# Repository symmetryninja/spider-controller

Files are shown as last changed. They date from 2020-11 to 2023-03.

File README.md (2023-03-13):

# spider-controller
A Raspberry Pi based linux system for driving ROS robots

I have a Teensy 3.2 setup as a native joystick.

There's a little hack in the code that when you push both left and right on the joypad buttons, it sends a keyboard `alt` keypress - this is to awaken a touchscreen when you don't have a keyboard plugged in.

## Ros component

This is a very basic joystick bridge, built on ROS2 Humble, it just publishes the joy commands to the ros subsystem.

## hardware Todo's

1. make the sd card more accesible
2. include tindie usbc charger
3. update case to suit charger

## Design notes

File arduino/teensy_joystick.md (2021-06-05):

# Some hacks for teensy Teensy 

Hacks are required to have the device report exactly what I want it to.

I figured this out [here on hamaluik.blog](https://github.com/hamaluik/blog.hamaluik.ca/blob/06a8439fae50b15cb966d33f3b0fdef9378a5c72/posts/2013-10-26-making-a-custom-teensy3-hid-joystick.md)

And used some values from the [freebsd diary usb HID here](https://www.freebsddiary.org/APC/usb_hid_usages.php)

Edits are all in the `Arduino/hardware/teensy/cores/teensy3` folder.

## Changes for file: `usb_desc.h`

After `#elif defined(USB_HID)` block:

```c++
#elif defined(USB_ARCADE)
	#define VENDOR_ID   0x16C0
	#define PRODUCT_ID	0x0489
	#define DEVICE_CLASS	0x03
	#define MANUFACTURER_NAME {'B', 'l', 'a', 'z', 'i', 'n', 'g', 'M', 'a', 'm', 'm', 'o', 't', 'h'}
	#define MANUFACTURER_NAME_LEN 14
	#define PRODUCT_NAME	{'W', 'e', 'd', 'c', 'a', 'd', 'e', ' ', 'C', 'o', 'n', 't', 'r', 'o', 'l', 'l', 'e', 'r'}
	#define PRODUCT_NAME_LEN  18
	#define EP0_SIZE			  64
	#define NUM_ENDPOINTS		 2
	#define NUM_USB_BUFFERS	   30
	#define NUM_INTERFACE		 1
	#define ARCADE_INTERFACE	  0 // Joystick
	#define ARCADE_ENDPOINT	   1
	#define ARCADE_SIZE		   16
	#define ARCADE_INTERVAL	   1
	#define ARCADE_DESC_OFFSET  (9)
	#define CONFIG_DESC_SIZE  (9 + 9+9+7)
	#define ENDPOINT1_CONFIG  ENDPOINT_TRANSIMIT_ONLY
```

## Changes for file: `usb_desc.c`

After first instance of `#endif // JOYSTICK_INTERFACE`

```c++
#ifdef ARCADE_INTERFACE
static uint8_t arcade_report_desc[] = {
	0x05, 0x01,					// USAGE_PAGE (Generic Desktop)
	0x09, 0x04,					// USAGE (Joystick)
	0xa1, 0x01,					// COLLECTION (Application)
	0x09, 0x04,					//   USAGE (Joystick)
	0xa1, 0x00,					//   COLLECTION (Physical)
	0x09, 0x30,					//	 USAGE (X)
	0x09, 0x31,					//	 USAGE (Y)
	0x09, 0x33,					//	 USAGE (Rx)
	0x09, 0x34,					//	 USAGE (Ry)
	0x75, 0x08,					//	 REPORT_SIZE (8)
	0x95, 0x04,					//	 REPORT_COUNT (4)
	0x45, 0x7f,					//	 PHYSICAL_MAXIMUM (127)
	0x35, 0x81,					//	 PHYSICAL_MINIMUM (-127)
	0x81, 0x02,					//	 INPUT (Data,Var,Abs)
	0x05, 0x09,					//	 USAGE_PAGE (Button)
	0x19, 0x01,					//	 USAGE_MINIMUM (Button 1)
	0x29, 0x10,					//	 USAGE_MAXIMUM (Button 16)
	0x15, 0x00,					//	 LOGICAL_MINIMUM (0)
	0x25, 0x01,					//	 LOGICAL_MAXIMUM (1)
	0x75, 0x01,					//	 REPORT_SIZE (1)
	0x95, 0x10,					//	 REPORT_COUNT (16)
	0x81, 0x02,					//	 INPUT (Data,Var,Abs)
	0xc0,						//   END_COLLECTION
	0xc0						// END_COLLECTION
};
#endif
```

After second instance of `#endif // JOYSTICK_INTERFACE`

```c++
#ifdef ARCADE_INTERFACE
static uint8_t arcade_report_desc[] = {
	0x05, 0x01,					// USAGE_PAGE (Generic Desktop)
	0x09, 0x04,					// USAGE (Joystick)
	0xa1, 0x01,					// COLLECTION (Application)
	0x09, 0x04,					//   USAGE (Joystick)
	0xa1, 0x00,					//   COLLECTION (Physical)
	0x09, 0x30,					//	 USAGE (X)
	0x09, 0x31,					//	 USAGE (Y)
	0x09, 0x33,					//	 USAGE (Rx)
	0x09, 0x34,					//	 USAGE (Ry)
	0x75, 0x08,					//	 REPORT_SIZE (8)
	0x95, 0x04,					//	 REPORT_COUNT (4)
	0x45, 0x7f,					//	 PHYSICAL_MAXIMUM (127)
	0x35, 0x81,					//	 PHYSICAL_MINIMUM (-127)
	0x81, 0x02,					//	 INPUT (Data,Var,Abs)
	0x05, 0x09,					//	 USAGE_PAGE (Button)
	0x19, 0x01,					//	 USAGE_MINIMUM (Button 1)
	0x29, 0x10,					//	 USAGE_MAXIMUM (Button 16)
	0x15, 0x00,					//	 LOGICAL_MINIMUM (0)
	0x25, 0x01,					//	 LOGICAL_MAXIMUM (1)
	0x75, 0x01,					//	 REPORT_SIZE (1)
	0x95, 0x10,					//	 REPORT_COUNT (16)
	0x81, 0x02,					//	 INPUT (Data,Var,Abs)
	0xc0,						//   END_COLLECTION
	0xc0						// END_COLLECTION
};
#endif
```

near the bottom of the file, add (just below the #ifdef JOYSTICK_INTERFACE ... #endif section)

```c++
#ifdef ARCADE_INTERFACE
		{0x2200, ARCADE_INTERFACE, arcade_report_desc, sizeof(arcade_report_desc)},
		{0x2100, ARCADE_INTERFACE, config_descriptor+ARCADE_DESC_OFFSET, 9},
#endif
```

## Changes for file: `usb_inst.cpp`

Below the `#ifdef JOYSTICK_INTERFACE` block

```c++
#ifdef USB_ARCADE
usb_arcade_class Arcade;
uint8_t usb_arcade_class::auto_send = 0;
#endif
```

## Changes for file: `WProgram.h`

Below `#include "usb_joystick.h"`

```c++
#include "usb_arcade.h"
```

Finally, in order to actually make the Arduino environment use the new arcade descriptors, add the following lines to the file Arduino/hardware/teensy/boards.txt (after the `teensy31.menu.usb.flightsim` entries):

```
teensy3.menu.usb.arcade.name=Wedcade Controller
teensy3.menu.usb.arcade.build.define0=-DUSB_ARCADE
teensy3.menu.usb.arcade.fake_serial=teensy_gateway
```

## Extra files
Copy `usb_arcade.h` & `usb_arcade.c` to `Arduino/hardware/teensy/cores/teensy3` folder.

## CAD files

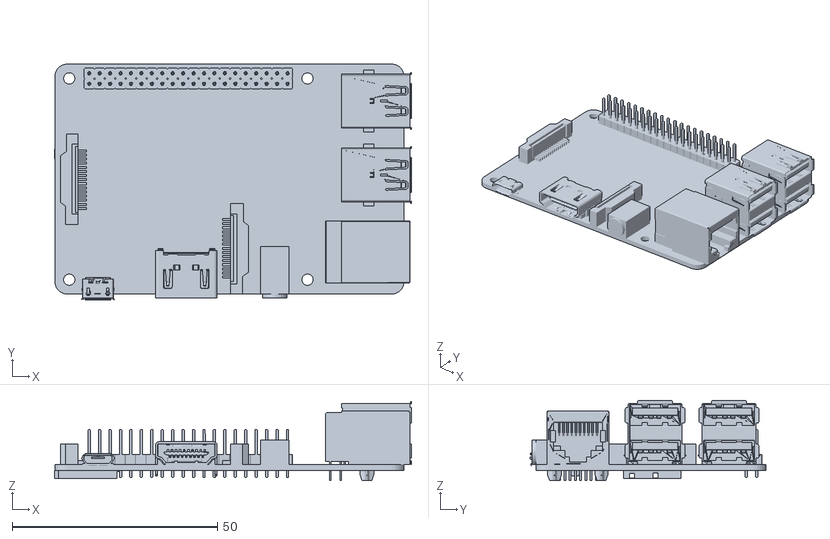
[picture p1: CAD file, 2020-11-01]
3dmodels/stl/pi3BModel.stl
86.9 x 57.4 x 19.6

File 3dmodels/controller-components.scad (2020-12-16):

  // momentary button & cap

  module component_momentary_button_12_cap() {
    translateZ(6) ccylinder(d = 13, h = 1.4);
    translateZ(8) ccylinder(d = 11.5, h = 5.2);
  }

  module component_momentary_button_12() {
    // base
    black() ccube([12,12,3.6]);
    // legs
    silver() mirrorX() mirrorY() translate([3.2, 6, -2]) ccube([1,1, 4.5]);
    // button
    translateZ(2.8) ccube([4,4,7]);
  }

  module component_slider(position = 50, for_cutout=false) {
    silver()
    ccube([45.2, 7.6, 7]);
    silver()
    translateX((position/100 * 30) - 15)
    translateZ(7.5) ccube([5, 1.2, 21.5]);
    if (for_cutout) {
      translateZ(7.5) ccube([46, 3, 21.5]);
    }
  }

  module component_momentary_barrel() {
    translateZ(-14.5) {
      black() translateZ(25.1) ccylinder(d = 5.9, h = 3.8);
      silver() translateZ(21.65) ccylinder(d = 4.7, h = 4.1);
      silver() translateZ(16.1) ccylinder(d = 6.5, h = 8);
      silver() translateZ(13) ccylinder(d = 9.4, h = 2.2);
      black() translateZ(9) ccylinder(d = 7.5, h = 6);
      silver() translateZ(3) mirrorX() translateX(1.9) ccube([0.6, 2, 6]);
    }
  }

  module component_barrel_power_switch(for_cutout = false) {
    full_H = 34;
    if (for_cutout) {
      // square block
      translateZ(full_H/2 - 23)
      ccube([15,22,15]);
    }
    black() {
      // barrel lg
      translateZ(full_H/2 - 12.5)
      ccylinder(d = 12, h = 15);
      // barrel sm
      translateZ(-3.25)
      ccylinder(d = 10, h = full_H-6.5);
      // sq button
      translateZ(full_H/2 - 5.5)
      ccube([11,11,11]);
      // sq barrel
      translateZ(full_H/2 - 7.5)
      ccube([15,15,6.5]);
    }
    silver() {
      // pins
      translateZ(-full_H/2) {
        translateY(3) ccube([2, 0.5, 10]);
        translateY(-3) ccube([2, 0.5, 10]);
      }
    }
  }

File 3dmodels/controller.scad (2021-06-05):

include <sn_tools.scad>
include <power_supplies.scad>
include <controller-components.scad>

/** project


  Phase 1: working with controller mounted and wired
    * core
      * screen frame fixes
        * side buttons (screen momentary switches)
        * increase space between frame and screen by 2 mm

  phase 2: joystick working

  phase 3: Charger

**/

/** Fixes
  * Top/all panel
    * cut a hole/holes for the xt60 pin mount.
  * underside panel
    * print outside up and raised completely off the bed for better removal of supports
*/


/** Scripting stuff **/
  batch_rendering = false;
  if (!batch_rendering) render_workspace();

  module render_workspace() {
    // $fn = 60;
    // sc_place_components();
    // sc_shell_screen_frame();
    // intersection() {
        purple() sc_shell_top();
        // translate([80, 55, 10]) ccube([40,40,15]);}
        translateZ(-5.2) blue() sc_shell_bottom_plate();
      translateZ(-10.1) red() sc_shell_bottom_battery();
  }

/** tooling modules **/

// parts to print
  module sc_parts_for_print() {
    // 
  }

/** globals **/
  sc_joystick_offset = [-113.5, -38, 2];
  sc_screen_offset = [0, 0, 10];
  sc_battery_rotation = [180, 0, 0];
  sc_battery_offset = [-42, 43, -7];
  sc_pi_offset = [30, -30, -8];
  sc_pi_rotation = [180, 0, -90];
  sc_teensy_offset = [-38, -40,-4];
  sc_teensy_rotation = [180, 0, -90];
  sc_bucky_offset = [-31, 0, -4];
  sc_bucky_rotation = [180, 0, 90];
  sc_trigger_offset = [145, -60, 0];

  sc_button_board_offset_R = [-110, 30, 5];
  sc_button_board_offset_L = [-sc_button_board_offset_R[0], sc_button_board_offset_R[1], sc_button_board_offset_R[2]];
  sc_button_board_rotation_Z = 90;

  sc_power_switch_offset= [67, -65, -15];
  sc_power_switch_rotation= [90, 0, 0];
  sc_xt60_offset = [-69,-65,-10];
  sc_xt60_rotation = [90,90,0];
  sc_screen_pi_lugs = [58,49];

/** non-print parts **/
  module sc_place_components() {
    // power switch
    translate(sc_power_switch_offset) rotate(sc_power_switch_rotation) component_barrel_power_switch();
    // xt60
    translate(sc_xt60_offset) rotate(sc_xt60_rotation) xt_60_plug_with_panel(cutouts_only = false);
    // buttons
      // left & right stick
      mirrorX() translate(sc_joystick_offset) sc_joystick();

    sc_button_board_L();
    sc_button_board_R();

    // batteries
      mirrorX() translate(sc_battery_offset) rotate(sc_battery_rotation) battery_holder_dual_18650(withBatteries=true);

    // screen 
      translate(sc_screen_offset) sc_screen();
    // boards
      // pi
      translate(sc_pi_offset) rotate(sc_pi_rotation) import("stl/pi3BModel.stl", convexity=3);

      // teensy
      translate(sc_teensy_offset) rotate(sc_teensy_rotation) sc_board_teensy();

      // bucky
      translate(sc_bucky_offset) rotate(sc_bucky_rotation) sc_bucky();

      // triggers
      mirrorX() translate(sc_trigger_offset) sc_triggers();
  }

  module sc_bucky() {
    green()
    difference() {
      ccube([37, 47, 1.5]);
      #sc_bucky_screws();
    }
  }

  module sc_bucky_screws(d=2.9, h=2) {
    mirrorX() translateX(15)
      translateY(42/2)
      ccylinder(h = h, d = d);
    translateX(-15)
      translateY(-38/2)
      ccylinder(h = h, d = d);
    translateX(15)
      translateY(-42/2)
      ccylinder(h = h, d = d);

  }

  module sc_bucky_test() {
    difference() {
      union() {
        hull() {
          sc_bucky_screws(d=6, h=2);
        }
        translateZ(4)
          sc_bucky_screws(d=6, h=8);
      }
      union() {
        sc_bucky_screws(h = 20);
      }
    }
  }

// components

  module sc_pushbutton(cap_color="white", os = 0) {
    translateZ(1.5)
    color(cap_color) {
      ccylinder(d=9 + os, h=14.5);
      translateZ(-3.7) ccylinder(d=12 + os, h=7.2);
    }
  }
  
  module sc_button_board_R() {
    translate(sc_button_board_offset_R) sc_button_board();
  }

  module sc_button_board_L() {
    translate(sc_button_board_offset_L) mirror([1,0,0]) sc_button_board(col_1="DarkSlateGray", col_2="DarkSlateGray", col_3="DarkSlateGray", col_4="DarkSlateGray");
  }

  module sc_button_board_panel_extras() {
    translate(sc_button_board_offset_R) sc_button_board_panel_extra();
    translate(sc_button_board_offset_L) mirror([1,0,0]) sc_button_board_panel_extra();
  }

  module sc_button_board_panel_extra() {
    rotateZ(sc_button_board_rotation_Z)
    union() {
      translateZ(5.3) {
        make_drill_holes(size=[66,46,9], shaftD=6);
        translate([-13.68, 0.7, 0])
        ccylinder(d = 6, h = 9);
      }
    }
  }

  module sc_button_board_cutouts() {
    translate(sc_button_board_offset_R) sc_button_board_cutout();
    translate(sc_button_board_offset_L) mirror([1,0,0]) sc_button_board_cutout();
  }

  module sc_button_board_cutout() {
    rotateZ(sc_button_board_rotation_Z) {
      // screws
      make_drill_holes(size=[66,46,25], shaftD=2.6);

      // slider cut out
      translate(sc_slider_R_offset) rotateZ(90) component_slider(for_cutout=true);
    }

    // buttons
    sc_button_board(os=1.5);
  }

  sc_trigger_R_offset = [0, -20, -12];
  sc_button_group_R_offset = [-20, 0, 7];
  sc_slider_R_offset = [24.85, 0, 4.5];

  module sc_button_board(col_1="DarkSlateGray", col_2="red", col_3="green", col_4="yellow", os=0) {
    rotateZ(sc_button_board_rotation_Z) {
      // green board
      rotateZ(90) make_protoboard_50_70();
      // iec box
      translate([23,0,-6])
      black() ccube([9, 28, 9.9]);
      // right slider
      translate(sc_slider_R_offset) rotateZ(90) component_slider();
      // right x buttons
        translate([11.5, -19, 7])
          sc_pushbutton("white", os=os);

        // 23.5 36.44
        translate([-1.44, -19, 7])
          sc_pushbutton("white", os=os);

      translate([-13.68, 0.7, 7]) {

        translate([12.7, 0, 0])
          sc_pushbutton(col_1, os=os);

        translate([-12.7, 0, 0])
          sc_pushbutton(col_2, os=os);

        translate([0, 12.7, 0])
          sc_pushbutton(col_3, os=os);

        translate([0, -12.7, 0])
          sc_pushbutton(col_4, os=os);
      }
    }
  }

  module sc_triggers() {
    // triggers
      translate([0,-5,6]) rotateX(90) component_momentary_barrel();
      translate([0,-5,-6]) rotateX(90) component_momentary_barrel();
  }

  // joystick
    module sc_joysticks_cutouts() {
      mirrorX() translate(sc_joystick_offset) sc_joystick(for_cutout = true);
    }

    module sc_joystick_inv(for_cutout = false) {
      mirror([1, 0, 0]) sc_joystick(for_cutout = for_cutout);
    }

    module sc_joystick(for_cutout = false) {
      // shaft
      silver()
      translateZ(12.5) ccylinder(d=8, h = 50);
      difference() {
        union(){
          // lock/unlock
          if (for_cutout) {
            // round
            ccylinder(d = 44, h = 40);
            //component cutout
            translateZ(-5)
            ccube([58, 58, 28]);
            translate([24, 0, -13.65]) 
              rotateY(90) rotateZ(-90)make_pie_slice(d=60, h = 6, angle=80);

            translate([20, 0, 15])
              ccube([5, 20, 20]);
            make_drill_holes(size=[39,39,25], shaftD=6);
            make_drill_holes(size=[39,39,40], shaftD=2.5);
          }
          else {
            //component cutout
            translateZ(-5)
            %ccube([58, 58, 28]);
            // square
            translate([0, 1, -1.25]) ccube([43, 45, 23]);
            make_drill_holes(size=[39,39,25], shaftD=5);

            black() {
              // round
              ccylinder(d = 42, h = 25);
              // crosshair
              translateZ(0.8) {
                ccube([1, 37, 25]);
                ccube([37, 1, 25]);
              }
            }
            translate([24, 0, -5]) {
              rotateY(90) rotateZ(-90)make_pie_slice(d=40, h = 4.5, angle=70);
              rotateY(90) rotateZ(-10)make_pie_slice(d=30, h = 3, angle=200);
              translateZ(16) ccube([3.5, 6, 20]);
            }
          }
        }
        union() {
          if (!for_cutout) black() sc_joystick_cutouts();
        }
      }
    }

    module sc_joystick_cutouts() {
      // top screws
      make_drill_holes(size=[39,39,30], shaftD=2.5);

      // upper cavity
      difference() {
        hull() {
          translateZ(13)
          ccube([30, 22, 1]);
          translateZ(5)
          ccube([25, 15, 1]);
        }
        translateZ(-5)
        rotateY(90)
        ccylinder(d = 30, h = 35);
      }
    }


  // screen
    module sc_screen(for_cutout=false) {
      difference() {
        union() {
          black() {
            // panel
            translateZ(2.2)
            ccube([167, 102, 6.18]);
            
            // power plug
            translate([67.5,-20.5,-5]) ccube([10,15, 20]);

            // usb touch plug
            translate([65,20.5,-5]) ccube([15,20, 20]);
            
            // side buttons
            translate([-77.5, 0, -7]) ccube([13, 55, 15]);
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

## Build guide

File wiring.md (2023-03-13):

# Wiring 

## Button pad wiring

## Button pads

| underside Pin Layout |  left layout | right layout |
| - | - | - |
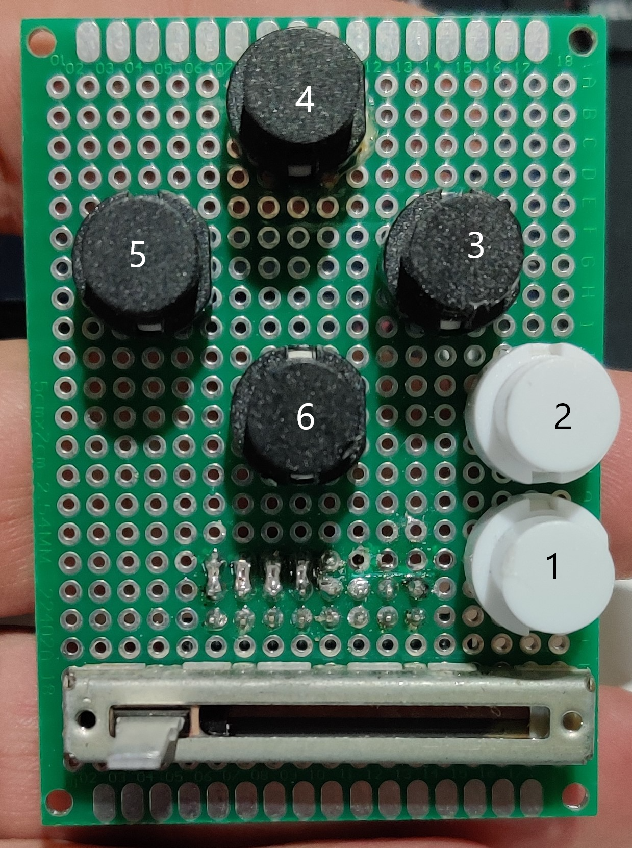
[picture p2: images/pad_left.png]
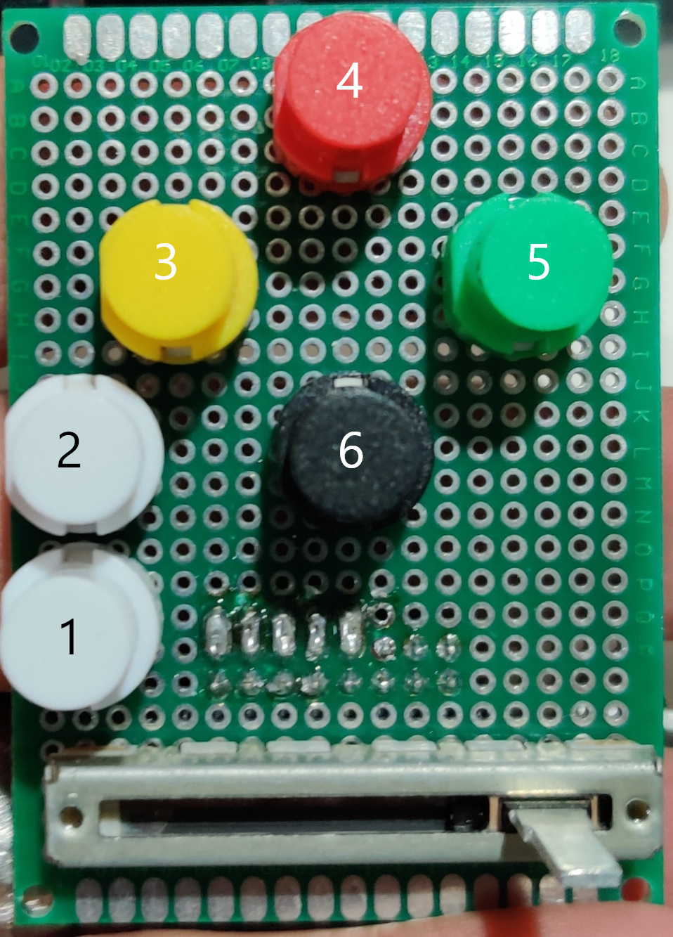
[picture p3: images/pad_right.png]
|  |  |  |

| Pin | purpose | Teensy Pin L  | Teensy Pin R |
|-|-|-|-|
| 0 | negative | A GND | A GND |
| 1 | positive | 3.3 | 3.3 |
| 2 | stick button  | 20 | nc |
| 3 | stick 0 | (17) A3 | A10 |
| 4 | stick 1 | (18) A4 | A11 |
| 5 | slide | (19) A5 | A14 |
| 6 | trigger T | 21 | 3 |
| 7 | trigger B | 22 | 2 |
| 8 | nc | | |
| 9 | nc | | |
| 10 | button 6 | 10 | 9 |
| 11 | button 5 | 11 | 8 |
| 12 | button 4 | 12 | 7 |
| 13 | button 3 | 23 | 6 |
| 14 | button 2 | 16 | 5 |
| 15 | button 1 | 15 | 4 |

## Teensy pinouts

|Teensy front|teensy back|
|-|-|
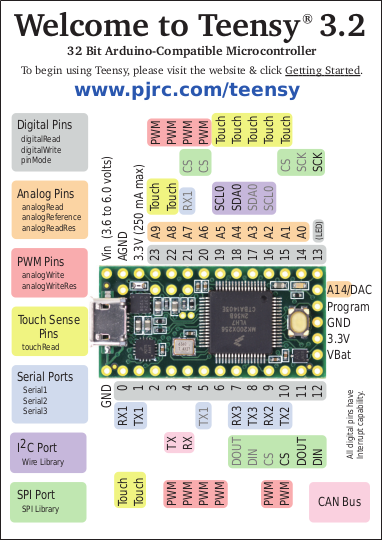
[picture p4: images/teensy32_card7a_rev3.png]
teensya
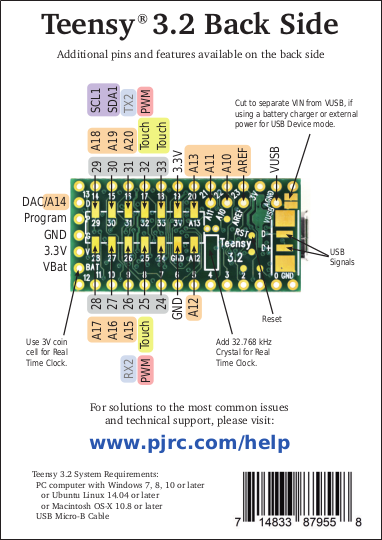
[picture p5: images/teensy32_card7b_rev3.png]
teensyb
| |  |

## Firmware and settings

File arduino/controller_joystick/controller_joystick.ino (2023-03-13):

// #include <Timer.h>                  // A rather useful timer library to offset the comms loop requirement to the motion requirement

// pin definitions 
  #define L_STICK_UD      A3
  #define L_STICK_LR      A4
  #define L_SLIDE         A5
  #define L_TRIGGER_T     21
  #define L_TRIGGER_B     22
  #define L_BUTTON_1      15
  #define L_BUTTON_2      16
  #define L_BUTTON_3      23
  #define L_BUTTON_4      12
  #define L_BUTTON_5      11
  #define L_BUTTON_6      10

  #define R_STICK_UD      A10
  #define R_STICK_LR      A11
  #define R_SLIDE         A14
  #define R_TRIGGER_T       2
  #define R_TRIGGER_B       3
  #define R_BUTTON_1        4
  #define R_BUTTON_2        5
  #define R_BUTTON_3        6
  #define R_BUTTON_4        9
  #define R_BUTTON_5        8
  #define R_BUTTON_6        7

/* input filtering */
  #define AFILTER 16
  #define L_STICK_UD_MIN 80
  #define L_STICK_UD_MID 520
  #define L_STICK_UD_MAX 905
  #define L_STICK_LR_MIN 910
  #define L_STICK_LR_MID 480
  #define L_STICK_LR_MAX 55
  #define R_STICK_UD_MIN 80
  #define R_STICK_UD_MID 500
  #define R_STICK_UD_MAX 905
  #define R_STICK_LR_MIN 905
  #define R_STICK_LR_MID 471
  #define R_STICK_LR_MAX 55

/* general stuff */
  int minRefreshCycle = 200; //hz
  uint16_t loops = 0;

/* state struct */
  struct ControllerState {
    uint16_t LStick_UD = 0;
    uint16_t LStick_LR = 0;
    uint16_t LSlide = 0;

    bool LTriggerT = false;
    bool LTriggerB = false;

    bool LButton1 = false;
    bool LButton2 = false;
    bool LButton3 = false;
    bool LButton4 = false;
    bool LButton5 = false;
    bool LButton6 = false;
    //right
    uint16_t RStick_UD = 0;
    uint16_t RStick_LR = 0;
    uint16_t RSlide = 0;

    bool RTriggerT = false;
    bool RTriggerB = false;

    bool RButton1 = false;
    bool RButton2 = false;
    bool RButton3 = false;
    bool RButton4 = false;
    bool RButton5 = false;
    bool RButton6 = false;
  };

ControllerState lastState;
ControllerState currentState;

void setup() {
  Serial.begin(115200);
  Joystick.useManualSend(true);

  pinMode (L_TRIGGER_T, INPUT_PULLUP);
  pinMode (L_TRIGGER_B, INPUT_PULLUP);
  pinMode (L_BUTTON_1, INPUT_PULLUP);
  pinMode (L_BUTTON_2, INPUT_PULLUP);
  pinMode (L_BUTTON_3, INPUT_PULLUP);
  pinMode (L_BUTTON_4, INPUT_PULLUP);
  pinMode (L_BUTTON_5, INPUT_PULLUP);
  pinMode (L_BUTTON_6, INPUT_PULLUP);

  pinMode (R_TRIGGER_T, INPUT_PULLUP);
  pinMode (R_TRIGGER_B, INPUT_PULLUP);
  pinMode (R_BUTTON_1, INPUT_PULLUP);
  pinMode (R_BUTTON_2, INPUT_PULLUP);
  pinMode (R_BUTTON_3, INPUT_PULLUP);
  pinMode (R_BUTTON_4, INPUT_PULLUP);
  pinMode (R_BUTTON_5, INPUT_PULLUP);
  pinMode (R_BUTTON_6, INPUT_PULLUP);
}

void loop() {
  getState();
  compareState();
  loops = (loops + 1) & 0xFFFF;
  delay(1000/minRefreshCycle);
}

void compareState() {
  if (!(
    currentState.LStick_UD == lastState.LStick_UD &&
    currentState.LStick_LR == lastState.LStick_LR &&
    currentState.LSlide == lastState.LSlide &&
    currentState.LTriggerT == lastState.LTriggerT &&
    currentState.LTriggerB == lastState.LTriggerB &&
    currentState.LButton1 == lastState.LButton1 &&
    currentState.LButton2 == lastState.LButton2 &&
    currentState.LButton3 == lastState.LButton3 &&
    currentState.LButton4 == lastState.LButton4 &&
    currentState.LButton5 == lastState.LButton5 &&
    currentState.LButton6 == lastState.LButton6 &&
    currentState.RStick_UD == lastState.RStick_UD &&
    currentState.RStick_LR == lastState.RStick_LR &&
    currentState.RSlide == lastState.RSlide &&
    currentState.RTriggerT == lastState.RTriggerT &&
    currentState.RTriggerB == lastState.RTriggerB &&
    currentState.RButton1 == lastState.RButton1 &&
    currentState.RButton2 == lastState.RButton2 &&
    currentState.RButton3 == lastState.RButton3 &&
    currentState.RButton4 == lastState.RButton4 &&
    currentState.RButton5 == lastState.RButton5 &&
    currentState.RButton6 == lastState.RButton6
  )) {
    outState();
    joystick710Send();
    mergeState();
  }

}

void joystick710Send() {
  // analogs
  Joystick.X(currentState.LStick_LR);
  Joystick.Y(currentState.LStick_UD);
  Joystick.Zrotate(currentState.RStick_UD);
  Joystick.Z(currentState.RStick_LR);
  Joystick.sliderLeft(currentState.LSlide);
  Joystick.sliderRight(currentState.RSlide);

  // hat
  // -1 - aka nothing touched
  int hatState = -1;
  if (currentState.LButton4) hatState = 0;
  if (currentState.LButton3) hatState = 90;
  if (currentState.LButton6) hatState = 180;
  if (currentState.LButton5) hatState = 270;
  if (currentState.LButton4 && currentState.LButton3) hatState = 45;
  if (currentState.LButton3 && currentState.LButton6) hatState = 135;
  if (currentState.LButton6 && currentState.LButton5) hatState = 225;
  if (currentState.LButton5 && currentState.LButton4) hatState = 315;

  Joystick.hat(hatState);
  // pushbuttons
  Joystick.button(5, currentState.LTriggerT);
  Joystick.button(7, currentState.LTriggerB);
  Joystick.button(9, currentState.LButton1);
  Joystick.button(11, currentState.LButton2);
  Joystick.button(6, currentState.RTriggerT);
  Joystick.button(8, currentState.RTriggerB);
  Joystick.button(10, currentState.RButton1);
  Joystick.button(12, currentState.RButton2);
  Joystick.button(1, currentState.RButton3);
  Joystick.button(4, currentState.RButton4);
  Joystick.button(3, currentState.RButton5);
  Joystick.button(2, currentState.RButton6);
  
  Joystick.send_now();
  
  // special override for keyboard hat left & right to force the screen to wake after deep sleep
  if (currentState.LButton3 && currentState.LButton5) {
    Keyboard.set_modifier(MODIFIERKEY_ALT);
    Keyboard.send_now();
    Keyboard.set_modifier(0);
    Keyboard.send_now();
  }
}

void mergeState() {
  lastState.LStick_UD = currentState.LStick_UD;
  lastState.LStick_LR = currentState.LStick_LR;
  lastState.LSlide = currentState.LSlide;
  lastState.LTriggerT = currentState.LTriggerT;
  lastState.LTriggerB = currentState.LTriggerB;
  lastState.LButton1 = currentState.LButton1;
  lastState.LButton2 = currentState.LButton2;
  lastState.LButton3 = currentState.LButton3;
  lastState.LButton4 = currentState.LButton4;
  lastState.LButton5 = currentState.LButton5;
  lastState.LButton6 = currentState.LButton6;
  lastState.RStick_UD = currentState.RStick_UD;
  lastState.RStick_LR = currentState.RStick_LR;
  lastState.RSlide = currentState.RSlide;
  lastState.RTriggerT = currentState.RTriggerT;
  lastState.RTriggerB = currentState.RTriggerB;
  lastState.RButton1 = currentState.RButton1;
  lastState.RButton2 = currentState.RButton2;
  lastState.RButton3 = currentState.RButton3;
  lastState.RButton4 = currentState.RButton4;
  lastState.RButton5 = currentState.RButton5;
  lastState.RButton6 = currentState.RButton6;
}

void getState() {
  // get the analog values with filter & min/max mapping
  currentState.LStick_UD = analogMapFilter(analogRead(L_STICK_UD), L_STICK_UD_MIN, L_STICK_UD_MID, L_STICK_UD_MAX);
  currentState.LStick_LR = analogMapFilter(analogRead(L_STICK_LR), L_STICK_LR_MIN, L_STICK_LR_MID, L_STICK_LR_MAX);

  currentState.RStick_UD = analogMapFilter(analogRead(R_STICK_UD), R_STICK_UD_MIN, R_STICK_UD_MID, R_STICK_UD_MAX);
  currentState.RStick_LR = analogMapFilter(analogRead(R_STICK_LR), R_STICK_LR_MIN, R_STICK_LR_MID, R_STICK_LR_MAX);
  
  currentState.LSlide = ((analogRead(L_SLIDE) / AFILTER) & 0xFFFF) * AFILTER;
  currentState.RSlide = ((analogRead(R_SLIDE) / AFILTER) & 0xFFFF) * AFILTER;

  currentState.LTriggerT = digitalRead(L_TRIGGER_T);
  currentState.LTriggerB = digitalRead(L_TRIGGER_B);
  currentState.LButton1 = digitalRead(L_BUTTON_1);
  currentState.LButton2 = digitalRead(L_BUTTON_2);
  currentState.LButton3 = digitalRead(L_BUTTON_3);
  currentState.LButton4 = digitalRead(L_BUTTON_4);
  currentState.LButton5 = digitalRead(L_BUTTON_5);
  currentState.LButton6 = digitalRead(L_BUTTON_6);

  currentState.RTriggerT = digitalRead(R_TRIGGER_T);
  currentState.RTriggerB = digitalRead(R_TRIGGER_B);
  currentState.RButton1 = digitalRead(R_BUTTON_1);
  currentState.RButton2 = digitalRead(R_BUTTON_2);
  currentState.RButton3 = digitalRead(R_BUTTON_3);
  currentState.RButton4 = digitalRead(R_BUTTON_4);
  currentState.RButton5 = digitalRead(R_BUTTON_5);
  currentState.RButton6 = digitalRead(R_BUTTON_6);
}

uint16_t analogMapFilter(long input, int low, int middle, int high) {
  if (input > middle) {
    return ((map(input, middle, high, 512,1023) / AFILTER) & 0xFFFF) * AFILTER;
  }
  else if (input < middle) {
    return ((map(input, low, middle, 0,512) / AFILTER) & 0xFFFF) * AFILTER;
  }
  return 512;
}

void outState() {
  Serial.println("");
  Serial.print("loops : ");
  Serial.println(loops);
  Serial.println("---- LEFT ----");
  Serial.print("LStick_UD : ");
  Serial.println(currentState.LStick_UD);
  Serial.print("LStick_LR : ");
  Serial.println(currentState.LStick_LR);
  Serial.print("LSlide : ");
  Serial.println(currentState.LSlide);
  Serial.print("LTriggerT : ");
  Serial.println(currentState.LTriggerT);
  Serial.print("LTriggerB : ");
  Serial.println(currentState.LTriggerB);
  Serial.print("LButton1 : ");
  Serial.println(currentState.LButton1);
  Serial.print("LButton2 : ");
  Serial.println(currentState.LButton2);
  Serial.print("LButton3 : ");
  Serial.println(currentState.LButton3);
  Serial.print("LButton4 : ");
  Serial.println(currentState.LButton4);
  Serial.print("LButton5 : ");
  Serial.println(currentState.LButton5);
  Serial.print("LButton6 : ");
  Serial.println(currentState.LButton6);
  Serial.println("");
  Serial.println("---- RIGHT ----");
  Serial.print("RStick_UD : ");
  Serial.println(currentState.RStick_UD);
  Serial.print("RStick_LR : ");
  Serial.println(currentState.RStick_LR);
  Serial.print("RSlide : ");
  Serial.println(currentState.RSlide);
  Serial.print("RTriggerT : ");
  Serial.println(currentState.RTriggerT);
  Serial.print("RTriggerB : ");
  Serial.println(currentState.RTriggerB);
  Serial.print("RButton1 : ");
  Serial.println(currentState.RButton1);
  Serial.print("RButton2 : ");
  Serial.println(currentState.RButton2);
  Serial.print("RButton3 : ");
  Serial.println(currentState.RButton3);
  Serial.print("RButton4 : ");
  Serial.println(currentState.RButton4);
  Serial.print("RButton5 : ");
  Serial.println(currentState.RButton5);
  Serial.print("RButton6 : ");
  Serial.println(currentState.RButton6);

}

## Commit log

2020-11-01 added all the components, started building a mock of the outer frame
    [controller.scad, pi3BModel.stl]
2020-11-14 lots of work on the inner frame
    [controller-components.scad, controller.scad]
2020-12-16 basically made all the things
    [controller-components.scad, controller.scad]
2021-01-17 models, docs and some arduino testing \ \ heaps of changes to the 3d models - ready to print!\ updated the docs for the wiring of all the buttons on the teensy \ built button panels and started testi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
    [controller.scad]
2021-01-18 working on L side button panels
2021-01-31 got the joystick working nicely
    [controller.scad]
2021-06-05 a bunch of fixes
    [controller.scad]
